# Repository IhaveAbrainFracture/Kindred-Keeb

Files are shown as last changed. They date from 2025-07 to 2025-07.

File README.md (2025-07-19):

# Kindred-Keeb
A keyboard themed and designed around the league of legends character Kindred, made for a certain someone <3







# why i made this
So the chronic ado fan this is going to is a keyboard fan and arguably a nerd in all things keyboard related and im not, this project was in part 1. to make a rly good gift but even more 2. to understand keyboards (the in's and the out's) such that when she eventually starts rambling again i can understand all the keyboard things she spews out.

View the full cad here (open in a new tab) : https://cad.onshape.com/documents/49660f55174e9c1ee612018b/w/865d86d8a66051a73309fb28/e/2b79c125cb158cfc9eb8a47f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

# Specificaton (Firmware)
1. 3 LAYERS OF FULL CUSTOMISABILITY!!!!!
2. 5 intergrated macros
3. kmk and fully open source
   


# Specifications (Electronics)
1. Hot swappable (you dont need to get married to the first switch you solder)
2. cool silk layer
3. run by a pico


# Specifications (Mechanical)
1. minimal bolts and others
2. textured arm rest that is magnetically held
3. only 4 major printed parts
4. custom keycaps
5. very thematicaly/lore accurate
   




# instructions to build
1.using the dowels and such attach the 2 major case and plate parts together then if possible 'melt' then together (like press a iron on both or smthing)

2. in the allocated area insert the insert nuts
   
3.cut and place the foam in the alloacted area then place the pcb on the groves outlines for it

4. place the fully assembled plate ontop of the pcb before placing all the switches
   
5. place the plate pcb sandwitch on the case and bolt into the allocated bolt holes and pray

# BOM 
| Item | Amount | Cost (AUD) | Cost (USD) | Link |
|---|---|---|---|---|
|Magnets| 50 (i cant order less)  | $3.32 | .. | [here](https://www.aliexpress.com/item/1005009515673951.html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"order"%3A"-1"%2C"eval"%3A"1"%7D&pdp_npi=4%40dis%21AUD%215.35%213.32%21%21%213.43%212.13%21%402101c5bf17528901380865997ea1e8%2112000049339085641%21sea%21AU%216189345413%21X&curPageLogUid=kPWgozpKm8qq&utparam-url=scene%3Asearch%7Cquery_from%3A) |
| Stabilisers|  1x | 9.69 | | [Here](https://www.aliexpress.com/item/1005009309795353.html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) |
| Akko blue switches | 45x | 23.19 | | [here](https://www.aliexpress.com/item/1005005514262670.html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"cart2PdpParams"%3A%7B"pdpBusinessMode"%3A"retail"%7D%7D) |
| Keycaps 132 key purple  | 1x | 20.61 | | [here](https://www.aliexpress.com/item/1005004537134105.html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) |
|  Raspberry pi pico | 1x | 2.84 | | [here](https://www.aliexpress.com/item/1005008478649106.html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) |
| 50 m2 bolts| 1x | 2.29 | | [here](https://www.aliexpress.com/item/32810872544.html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) |
| 50x 3.2 od m2 insert nut  | x1 | 2.29 | |  [here](https://www.aliexpress.com/item/1005008666672949.html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) |
| 100x n4148 diodes  | x1 | 2.79 | |  [here](https://www.aliexpress.com/item/4000142272546.html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) |
|  desoldering braid wick | x1 | 4.43 | | [here](https://www.aliexpress.com/item/1005006427770026.html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) |
| Akko purple switch  | 45x |  25.59 | | [here](https://www.aliexpress.com/item/1005007551750020.html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) |
| kailh hot swap socket | 70x | 5.54 | |  [here](https://www.aliexpress.com/item/1005007225352311.html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) |
| 2mm thick eva foam  | 1x | 4.79 | | [here](https://www.aliexpress.com/item/1005009318717019.html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)  |
|  silent lemon v3 switch  |  10x  |  4.86 | | [here](https://www.aliexpress.com/item/1005007459638140.html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)  |
| PCB | 5x | 59.86 | | 
  |
|  3D Printing   |   a lot     |     Free         |            |   Printing legion   |

Total: 

AUD: 181.82 (WITH SHIPPING)

USD:118.84 (WITH SHIPPING)

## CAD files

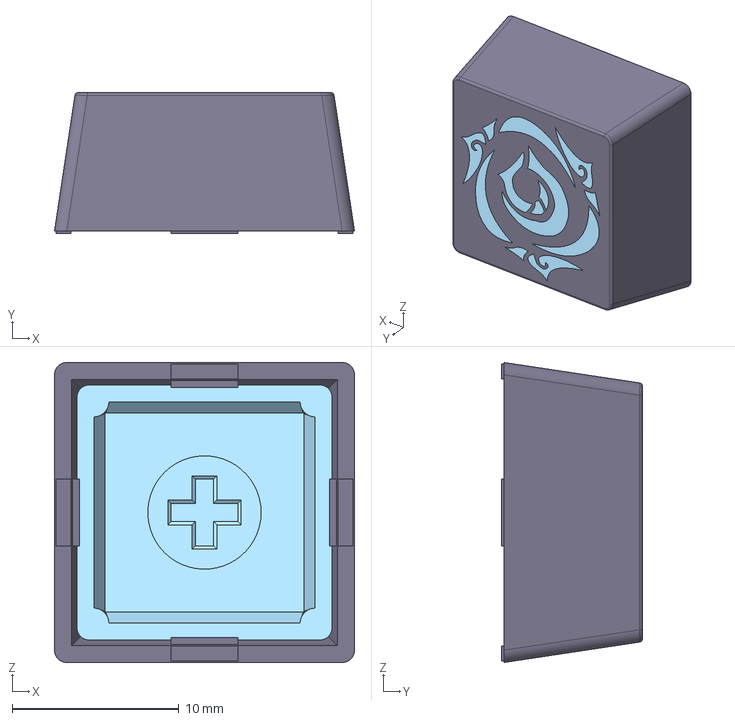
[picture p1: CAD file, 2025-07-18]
Production files/CAD FILES/Keycap (hunters mark).step
18.0 x 8.45 x 18.0 mm

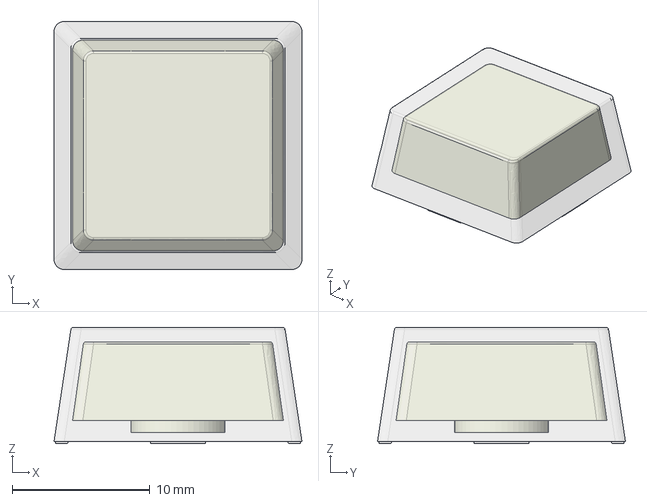
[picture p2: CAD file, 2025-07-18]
Production files/CAD FILES/Keycap.step
18.0 x 18.0 x 8.45 mm
beschr. Kappe Abdeckung
beschr. Kappe Unterteil

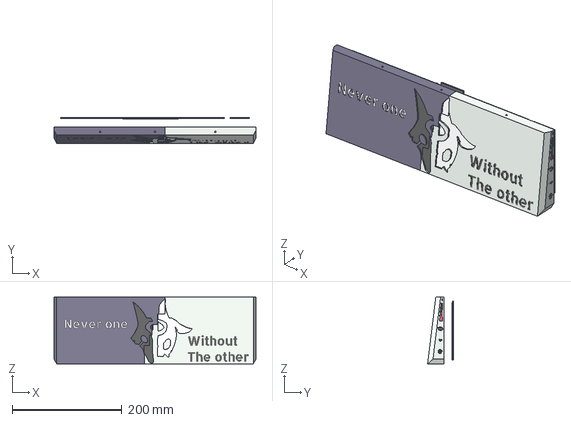
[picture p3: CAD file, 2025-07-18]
Production files/CAD FILES/Keyboard case.step
367.9 x 47.0 x 121.6 mm

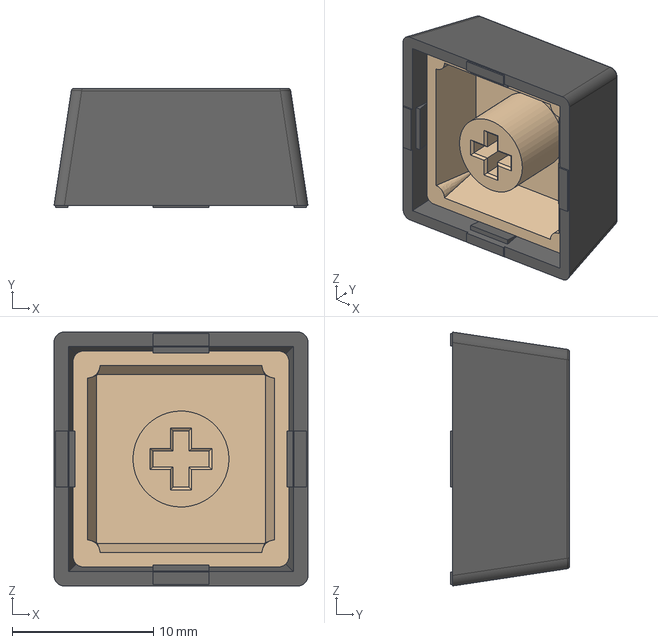
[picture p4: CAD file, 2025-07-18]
Production files/CAD FILES/precision keycap.step
18.0 x 8.45 x 18.0 mm

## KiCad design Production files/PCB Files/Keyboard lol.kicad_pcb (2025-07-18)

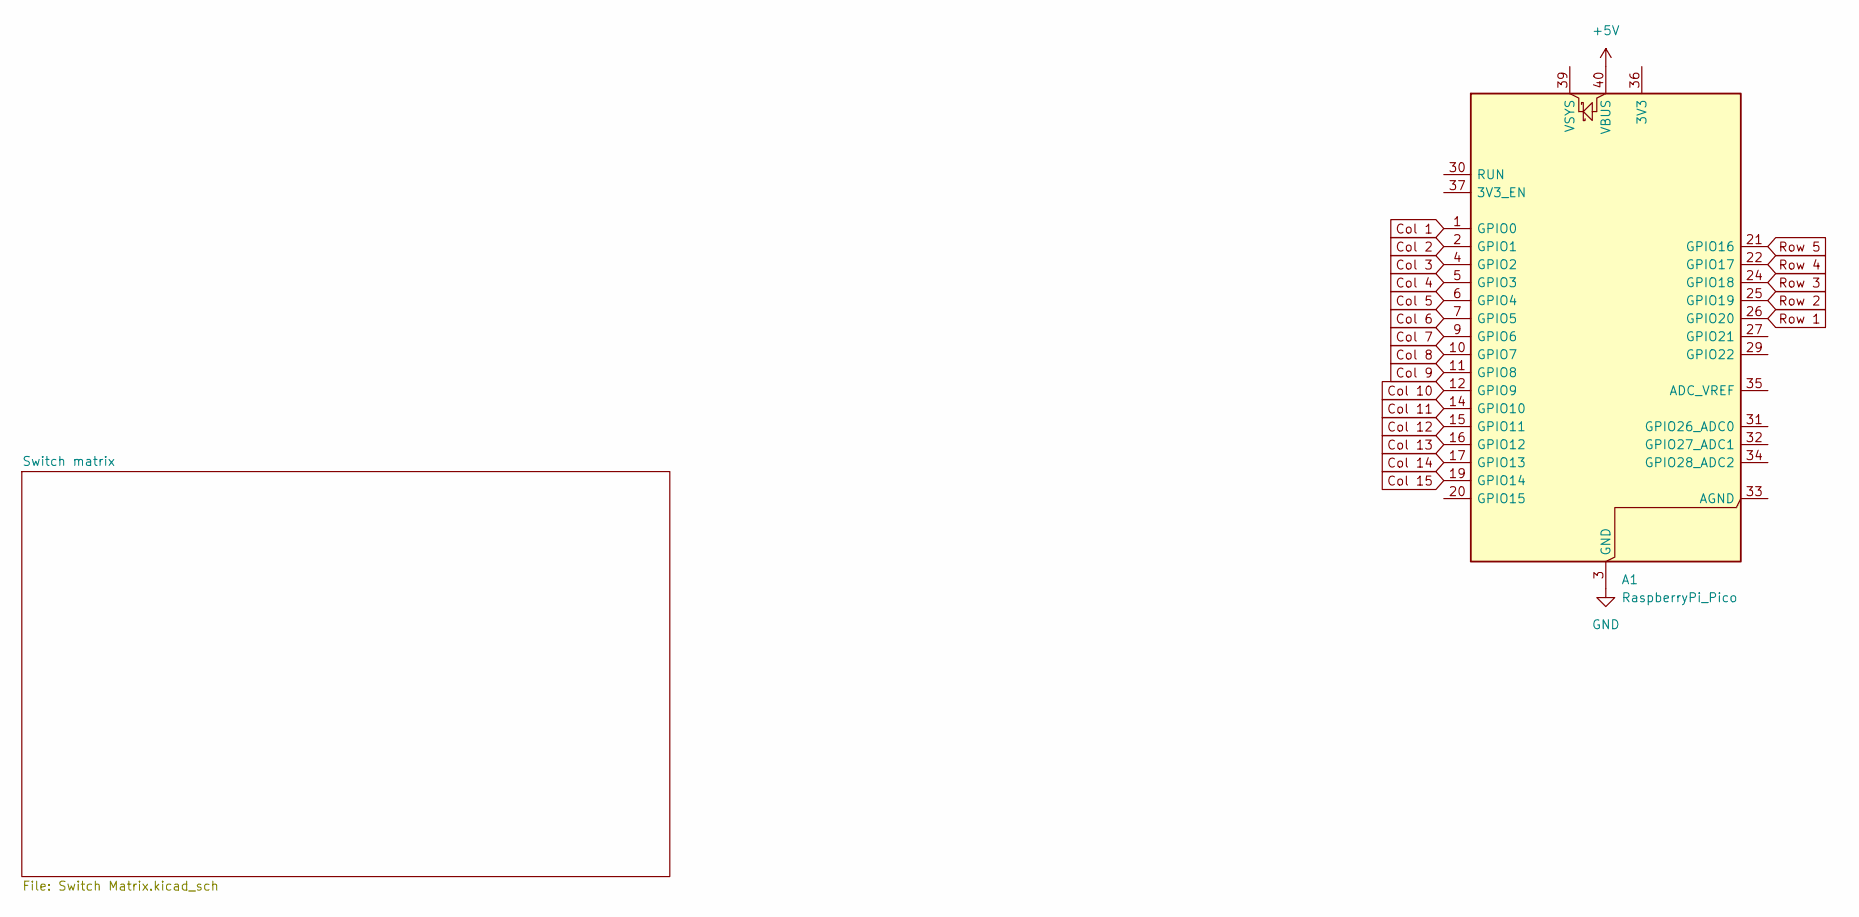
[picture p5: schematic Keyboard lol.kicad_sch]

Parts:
A1: RaspberryPi_Pico; RaspberryPi_Pico_Common_THT

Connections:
+5V: A1.40 (VBUS)
Col 1: A1.1 (GPIO0); also elsewhere on the board
Col 2: A1.2 (GPIO1); also elsewhere on the board
Col 3: A1.4 (GPIO2); also elsewhere on the board
Col 4: A1.5 (GPIO3); also elsewhere on the board
Col 5: A1.6 (GPIO4); also elsewhere on the board
Col 6: A1.7 (GPIO5); also elsewhere on the board
Col 7: A1.9 (GPIO6); also elsewhere on the board
Col 8: A1.10 (GPIO7); also elsewhere on the board
Col 9: A1.11 (GPIO8); also elsewhere on the board
Col 10: A1.12 (GPIO9); also elsewhere on the board
Col 11: A1.14 (GPIO10); also elsewhere on the board
Col 12: A1.15 (GPIO11); also elsewhere on the board
Col 13: A1.16 (GPIO12); also elsewhere on the board
Col 14: A1.17 (GPIO13); also elsewhere on the board
GND: A1.3 (GND), A1.8 (GND), A1.13 (GND), A1.18 (GND), A1.23 (GND), A1.28 (GND), A1.38 (GND)
Row 1: A1.26 (GPIO20); also elsewhere on the board
Row 2: A1.25 (GPIO19); also elsewhere on the board
Row 3: A1.24 (GPIO18); also elsewhere on the board
Row 4: A1.22 (GPIO17); also elsewhere on the board
Row 5: A1.21 (GPIO16); also elsewhere on the board

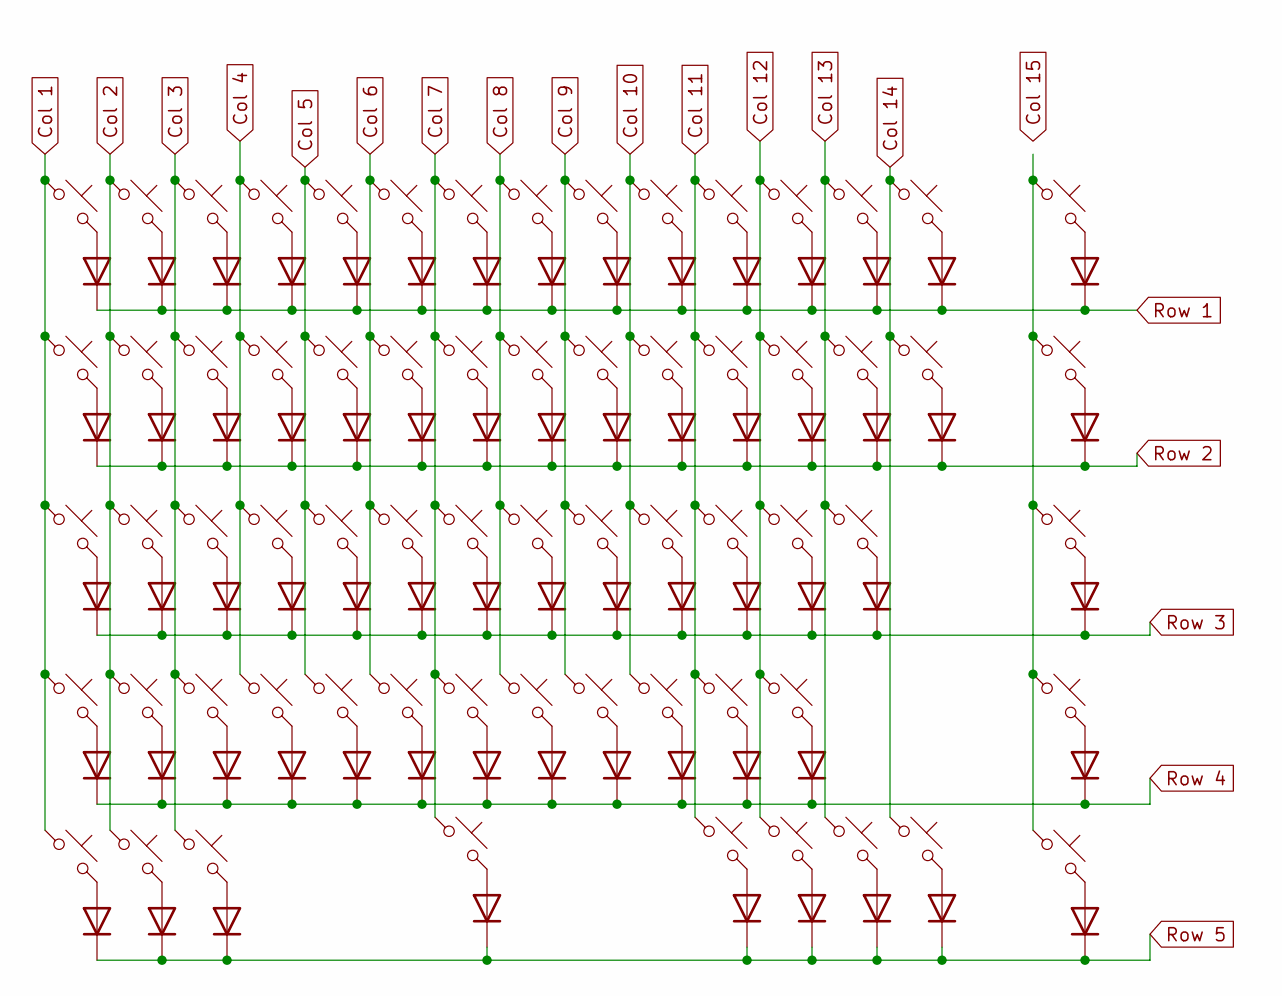
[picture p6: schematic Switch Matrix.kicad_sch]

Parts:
D1, D2, D3, D4, D5, D6, D7, D8, D9, D10, D11, D12, D13, D14, D15, D16, D17, D18, D19, D20, D21, D22, D23, D24, D25, D26, D27, D28, D30, D31, D32, D33, D34, D35, D36, D37, D38, D39, D40, D41, D42, D45, D46, D47, D48, D49, D50, D51, D52, D53, D54, D55, D56, D57, D58, D59, D60, D61, D62, D63, D64, D65, D66, D67, D68, D75: 1N4148; D_DO-35_SOD27_P7.62mm_Horizontal
SW1, SW14: SW_Push_45deg; MX-Hotswap-1.5U
SW2, SW3, SW4, SW5, SW6, SW7, SW8, SW9, SW10, SW11, SW12, SW13, SW15, SW17, SW18, SW19, SW20, SW21, SW22, SW23, SW24, SW25, SW26, SW27, SW30, SW32, SW33, SW34, SW35, SW36, SW37, SW38, SW39, SW40, SW41, SW45, SW46, SW47, SW48, SW49, SW50, SW51, SW52, SW53, SW54, SW55, SW56, SW57, SW58, SW60, SW75: SW_Push_45deg; MX-Hotswap-1U
SW16: SW_Push_45deg; MX-Hotswap-1.75U
SW28, SW31: SW_Push_45deg; MX-Hotswap-2.25U
SW42: SW_Push_45deg; MX-Hotswap-2.75U
SW59: SW_Push_45deg; MX-Hotswap-2U
SW61, SW62, SW63, SW65, SW66, SW67, SW68: SW_Push_45deg; MX-Hotswap-1.25U
SW64: SW_Push_45deg; MX-Hotswap-6.25U-ReversedStabilizers

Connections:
Col 1: SW1.1, SW16.1, SW31.1, SW46.1, SW61.1; also elsewhere on the board
Col 2: SW2.1, SW17.1, SW32.1, SW47.1, SW62.1; also elsewhere on the board
Col 3: SW3.1, SW18.1, SW33.1, SW48.1, SW63.1; also elsewhere on the board
Col 4: SW4.1, SW19.1, SW34.1, SW49.1; also elsewhere on the board
Col 5: SW5.1, SW20.1, SW35.1, SW50.1; also elsewhere on the board
Col 6: SW6.1, SW21.1, SW36.1, SW51.1; also elsewhere on the board
Col 7: SW7.1, SW22.1, SW37.1, SW52.1, SW64.1; also elsewhere on the board
Col 8: SW8.1, SW23.1, SW38.1, SW53.1; also elsewhere on the board
Col 9: SW9.1, SW24.1, SW39.1, SW54.1; also elsewhere on the board
Col 10: SW10.1, SW25.1, SW40.1, SW55.1; also elsewhere on the board
Col 11: SW11.1, SW26.1, SW41.1, SW56.1, SW65.1; also elsewhere on the board
Col 12: SW12.1, SW27.1, SW42.1, SW57.1, SW66.1; also elsewhere on the board
Col 13: SW13.1, SW28.1, SW58.1, SW67.1; also elsewhere on the board
Col 14: SW14.1, SW59.1, SW68.1; also elsewhere on the board
unnamed: D1.2 (A), SW1.2
unnamed: D2.2 (A), SW2.2
unnamed: D3.2 (A), SW3.2
unnamed: D4.2 (A), SW4.2
unnamed: D5.2 (A), SW5.2
unnamed: D6.2 (A), SW6.2
unnamed: D7.2 (A), SW7.2
unnamed: D8.2 (A), SW8.2
unnamed: D9.2 (A), SW9.2
unnamed: D10.2 (A), SW10.2
unnamed: D11.2 (A), SW11.2
unnamed: D12.2 (A), SW12.2
unnamed: D13.2 (A), SW13.2
unnamed: D14.2 (A), SW14.2
unnamed: D15.2 (A), SW15.2
unnamed: D16.2 (A), SW16.2
unnamed: D17.2 (A), SW17.2
unnamed: D18.2 (A), SW18.2
unnamed: D19.2 (A), SW19.2
unnamed: D20.2 (A), SW20.2
unnamed: D21.2 (A), SW21.2
unnamed: D22.2 (A), SW22.2
unnamed: D23.2 (A), SW23.2
unnamed: D24.2 (A), SW24.2
unnamed: D25.2 (A), SW25.2
unnamed: D26.2 (A), SW26.2
unnamed: D27.2 (A), SW27.2
unnamed: D28.2 (A), SW28.2
unnamed: D30.2 (A), SW30.2
unnamed: D31.2 (A), SW31.2
unnamed: D32.2 (A), SW32.2
unnamed: D33.2 (A), SW33.2
unnamed: D34.2 (A), SW34.2
unnamed: D35.2 (A), SW35.2
unnamed: D36.2 (A), SW36.2
unnamed: D37.2 (A), SW37.2
unnamed: D38.2 (A), SW38.2
unnamed: D39.2 (A), SW39.2
unnamed: D40.2 (A), SW40.2
unnamed: D41.2 (A), SW41.2
unnamed: D42.2 (A), SW42.2
unnamed: D45.2 (A), SW45.2
unnamed: D46.2 (A), SW46.2
unnamed: D47.2 (A), SW47.2
unnamed: D48.2 (A), SW48.2
unnamed: D49.2 (A), SW49.2
unnamed: D50.2 (A), SW50.2
unnamed: D51.2 (A), SW51.2
unnamed: D52.2 (A), SW52.2
unnamed: D53.2 (A), SW53.2
unnamed: D54.2 (A), SW54.2
unnamed: D55.2 (A), SW55.2
unnamed: D56.2 (A), SW56.2
unnamed: D57.2 (A), SW57.2
unnamed: D58.2 (A), SW58.2
unnamed: D59.2 (A), SW59.2
unnamed: D60.2 (A), SW60.2
unnamed: D61.2 (A), SW61.2
unnamed: D62.2 (A), SW62.2
unnamed: D63.2 (A), SW63.2
unnamed: D64.2 (A), SW64.2
unnamed: D65.2 (A), SW65.2
unnamed: D66.2 (A), SW66.2
unnamed: D67.2 (A), SW67.2
unnamed: D68.2 (A), SW68.2
unnamed: D75.2 (A), SW75.2
Row 1: D46.1 (K), D47.1 (K), D48.1 (K), D49.1 (K), D50.1 (K), D51.1 (K), D52.1 (K), D53.1 (K), D54.1 (K), D55.1 (K), D56.1 (K), D57.1 (K), D58.1 (K), D59.1 (K), D60.1 (K); also elsewhere on the board
Row 2: D1.1 (K), D2.1 (K), D3.1 (K), D4.1 (K), D5.1 (K), D6.1 (K), D7.1 (K), D8.1 (K), D9.1 (K), D10.1 (K), D11.1 (K), D12.1 (K), D13.1 (K), D14.1 (K), D15.1 (K); also elsewhere on the board
Row 3: D16.1 (K), D17.1 (K), D18.1 (K), D19.1 (K), D20.1 (K), D21.1 (K), D22.1 (K), D23.1 (K), D24.1 (K), D25.1 (K), D26.1 (K), D27.1 (K), D28.1 (K), D30.1 (K); also elsewhere on the board
Row 4: D31.1 (K), D32.1 (K), D33.1 (K), D34.1 (K), D35.1 (K), D36.1 (K), D37.1 (K), D38.1 (K), D39.1 (K), D40.1 (K), D41.1 (K), D42.1 (K), D45.1 (K); also elsewhere on the board
Row 5: D61.1 (K), D62.1 (K), D63.1 (K), D64.1 (K), D65.1 (K), D66.1 (K), D67.1 (K), D68.1 (K), D75.1 (K); also elsewhere on the board

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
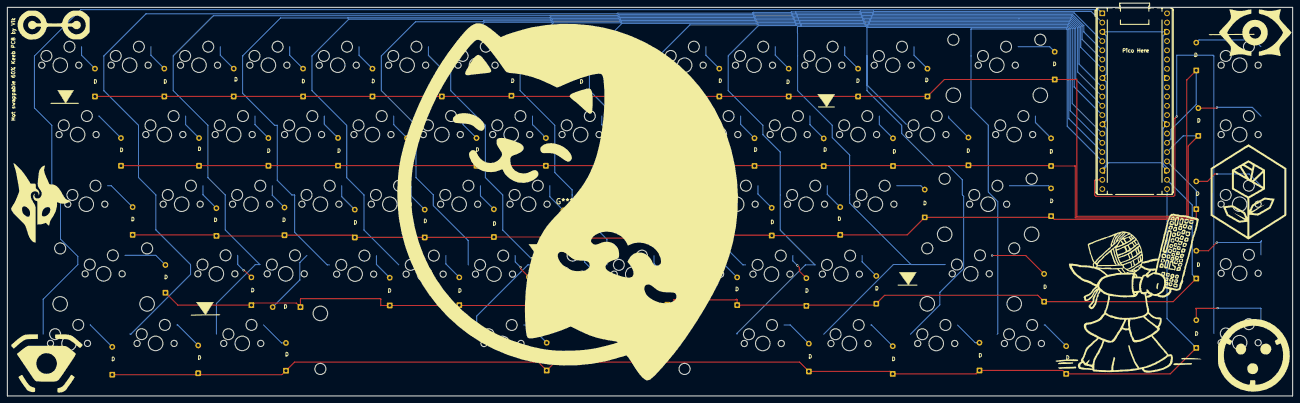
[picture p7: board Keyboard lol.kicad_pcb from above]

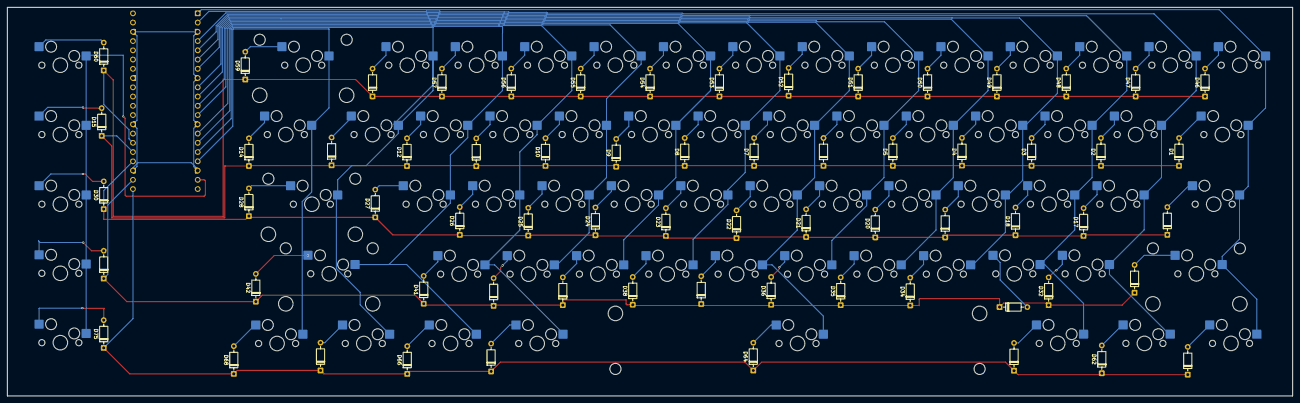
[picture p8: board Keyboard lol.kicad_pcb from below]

Board: 2 copper layers, 352.9 x 106.7 mm, 133 parts (132 on the bottom side), 87 nets.

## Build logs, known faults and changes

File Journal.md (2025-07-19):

---
title: "Kindred Keeb"
author: "TheVirtuoso (me)"
description: "A keyboard that thematicaly fits the charecter kindred from lol"
created_at: "13/07/25"
---

total hours ~ 45  (these hours are like not locked in locked in hours cos i was very non strict in time in reality this project could be done in 30h)

# background information that you may want to know to that some things make more sense
- kindred is a league of legends charecter who lore wise is just death
- the idea is when someone is about to die they can choose to me killed swiftly by lamb's bow or resist dead and fight wolf in more or less a bloodbath
- in the game one of her core mechanics is the mark of the hunted which is a big target sign
- in lol after picking a charecter you pick runes which slightly modify a charecter
- kindred is a top tier meta pick rn trust

# mildly important note
** So im updating the journal to reflect what ive done anything with "OLD:" is the old entry which i kept because its a little more authentic as it was done on the day (most likely at 12 or 1 AM) but for all non troll reasons read the new entry since its a better explainantion on what i did and how that went **

 OLD: so i've been procrastinating making and updating the journal for the first few days because just like today (15/07/25) ive staid up till 12pm to work on stuff either way ill recap the last 2 days which had me working on electronics (PCB)

# 13/07/25 2h
Old : i more or less spent this day just brainstorming what i was going to do because i knew i was going to make a custom keyboard for my gf but i didnt know what to theme it off of ect i came to the following conclusions after a hour of brainstorming
 - the keyboard is going to be based on a game preferably one with chatecters so i can theme it off her "main"
 - options include: Kindred, Cypher, kai'sa, The Engineneer and Clove
 - i want the pcb to be as good as possible so i can use it for myself later
 - most likely going to use tactile switches
 - i want it to be hot swappable
 - i should make accessories that add on to the keeb (arm rest)
   
New: 

this day was spent brainstorming the main take aways was that i knew the keeb (keyboard) was going to be based on a charecter from a game most likely league of legends or valorant ( in ended up being kindred from lol altho it was very close to being based on clove, the color profiles are below). Further more i knew i wanted the PCB to be good enough that it could be used in future projects meaning i wanted it to be versitile and high quality ie hot swappable and good layout
- 
- 
Above is the colour profile for clove

- 
- 

Above is the colour proflie for kindred

Theme wise i also had 2 options the duality, yin yang-ish theme or the butterflys and repetion theme (these being from kindred and clove respectfully)\
ultimatly i picked kindred cos ann (nickname) play way more lol then valo also i though it would be easier to design (i was wrong)

here were the broad design choices after deciding to base the keeb of kindred
- case divided into 2 parts (wolf and Lamb)
- 2 diffrent switchs one that heavy and loud/thocky and one thats light and silent
- the masks need to be somewhere, and the cool quotes
- it would be nice to have the keeb textured
- the mark of the hunted needs to be everywhere on keycaps and case

# 14/07/25 16h
  OLD: ill put photos here late but this day mostly consisted of research and making the schematics/pcb ill pop photos in the morning but more or less i have a terrible time trying to position and align everything, ultimatly i did get most of the pcb and schematics done. (funny note, i spent 1h just on messing with footprints) either way i think i ended this day with the matrix wired in the pcb and the footprints more or less is the right spot but nothing was connected to the pico and i still had to run through the 20 drc issues  also cleaned up the pcb specifically wiring everything to the pico, drc, and silk screen( i added so many easter eggs) i also posted the pcb to the atlier discord server for feedback and implemented that

New:
Started PCB it was mostly easy the core concepts are the same, im also hyper gratfull that i learnt how to wire matrixes and stuff early,

Schematic here:

-  
(fun fact you can make a seperate sheet for your schematic using "s" , thats were my matrix is)
I also experimented with the idea of leds but i just couldnt figure a way to make it fit the theme heres that schematic either way

- 
i also got most of the keyboard pcb done which looks like this
- 
you also might notice the fact that col 15 isnt connected in the matrix above and ye i just fixed that (18/07/25) 
with silk it looks like this
- 
- Explaination of silk (she loves cats, use to main cypher in valorant hence the abilitys in the corners, currently is training in kendo, and the kindred mask exists)
i also put stuff into the atelier discord for review and implemented that feedback.( to anyone who wants to also make a keyboard my suggestion is to pick the ai03 footprints and stick to them)

  # 15/07/25 10h
 OLD: i spend way to long cadding to make the case and all, ill add more stuff her later but its 12:30 and i need to get sleep cos i got stuff to do so ill update this with tmmrws update, ill also add photots and clean up spelling 

New: this day was spent cadding and designing i more or less spent this day messing around with cad stuff but the issue is i dont rly haev anything so show since i didnt take any screenshots so heres my proof
 
we love onshape history 

  # 16/07/25 5h
  OLD: trust me i did stuff but this is another i stayed up till 12 situation so ill update this later the tldr is the base of the case is more or less done its just design stuff lef
  
- New: again dont have alot to show here but i can replicate it:

 it was at this point i more or less had my main case done ( the shell more or less) i also started the arm rest which i do have photos of

 



   # 17/07/25 15h

 OLD:  this entry got deleted so like gotta add stuff
New: so this carries on to the next entry since i wrote 18 cos it was 1 am either way this day i finished all is not most of the design/cosmetic stuff best shown though photos, ill also be explaining some of the cool things



- so this is the mark of the hunted and i wanted it to be a core part of the case so its in the center and the middle

- 

- so this is a mix of wolfs and lambs mask with one of their most common voicelines "never one without the other" its also black and white to reflect the duality theme i started with

- 
- 

these are lol runes and are also the best/ most common rune build for kindred

- 
-  mark of the hunted custom keycap

-  

-  

- Arm rest modifications

- and with that i should be done in cad also note 



FOAMMMMMM!!!!!

  # 18/07/25 3h
  OLD: im going to sleep instead i swear update soon

  # 18/07/25 4h
OLD: gues what its not 12 an im done so i can spend time now cleaning the github

New: i didnt do too much other than clean the github and start and finish firmware which is here: (funny story i was doing firmware while in the hospital)


# 19/07/25
did bom and prob gonna submit today not counting time towards project

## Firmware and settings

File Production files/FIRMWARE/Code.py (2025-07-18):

print("Starting")

import board

from kmk.kmk_keyboard import KMKKeyboard
from kmk.keys import KC, Keyboard
from kmk.scanners import DiodeOrientation
from kmk.modules.macros import Macros
from kmk.modules.macros import Press, Release, Tap  #underdefined
from kmk.modules.layers import layers 

# all imports
keyboard = KMKKeyboard()
macros = Macros()
keyboard.modules.append(macros)
keyboard.col_pins = (board.GP0, board.GP1, board.GP2, board.GP3, board.GP4, board.GP5,board.GP6, board.GP7,board.GP8, board.GP9,board.GP10,board.GP11, board.GP12, board.GP13, board.GP14 )
keyboard.row_pins = (board.GP16, board.GP17, board.GP18, board.GP19, board.GP20)
keyboard.diode_orientation = DiodeOrientation.COL2ROW   # i think its col2row
keyboard.modules.append(layers)

PASTE =KC.MACRO(
  (
    KC.LCTL(KC.V)),
  )

COPY =KC.MACRO(
  (
    KC.LCTL(KC.C)),
  )


Ctrl_Tab =KC.MACRO(
  (
    KC.LCTL(KC.TAB)),
  )

Alt_Tab =KC.MACRO(
  (
    KC.LALT(KC.LTAB),
  )
)

SAVE = KC.MARCO (
    (
        KC.LCTL(KC.S)
    )
)

keyboard.keymap =     [ [
        KC.ESC,  KC.N1,   KC.N2,   KC.N3, KC.N4, KC.N5,   KC.N6,   KC.N7,   KC.N8,   KC.N9,   KC.N0,   KC.MINS, KC.EQL,  KC.BSPC, PASTE,
        KC.TAB,  KC.Q,   KC.W,    KC.E,    KC.R,    KC.T,    KC.Y,    KC.U,    KC.I,    KC.O,    KC.P,    KC.LBRC, KC.RBRC, KC.BSLS, COPY,
        KC.CAPS, KC.A,   KC.S,    KC.D,    KC.F,    KC.G,    KC.H,    KC.J,   KC.K,   KC.L,    KC.SCLN, KC.QUOT,          KC.ENT,  SAVE,
        KC.LSFT, KC.Z,    KC.X,   KC.C ,  KC.V,    KC.B,    KC.N,    KC.M,    KC.COMM, KC.DOT,  KC.SLSH,      KC.RSFT, KC.MO(1), Alt_Tab,
        KC.LCTL, KC.LGUI, KC.LALT,                            KC.SPC,                             KC.RALT, KC.MO(2), KC.MENU, KC.RCTL, Ctrl_Tab,
    ],
    # L1 function keys
    [
        KC.GRV,  KC.F1,   KC.F2,   KC.F3,   KC.F4,   KC.F5,   KC.F6,   KC.F7,   KC.F8,   KC.F9,   KC.F10,  KC.F11,  KC.F12,  KC.DEL,
        KC.TRNS, KC.TRNS, KC.UP,   KC.TRNS, KC.TRNS, KC.TRNS, KC.TRNS, KC.TRNS, KC.PSCR, KC.SLCK, KC.PAUS, KC.TRNS, KC.TRNS, KC.TRNS,
        KC.TRNS, KC.LEFT, KC.DOWN, KC.RGHT, KC.TRNS, KC.TRNS, KC.TRNS, KC.HOME, KC.PGDN, KC.PGUP, KC.END,  KC.TRNS,          KC.TRNS,
        KC.TRNS, KC.TRNS, KC.TRNS, KC.TRNS, KC.TRNS, KC.TRNS, KC.TRNS, KC.TRNS, KC.TRNS, KC.TRNS, KC.TRNS,          KC.TRNS, KC.TRNS,
        KC.TRNS, KC.TRNS, KC.TRNS,                            KC.TRNS,                            KC.TRNS, KC.TRNS, KC.TRNS, KC.TRNS,
    ],
    # Audio (might update for more stuff)
    [
        KC.TRNS, KC.TRNS, KC.TRNS, KC.TRNS, KC.TRNS, KC.TRNS, KC.TRNS, KC.TRNS, KC.TRNS, KC.TRNS, KC.TRNS, KC.TRNS, KC.TRNS, KC.TRNS,
        KC.TRNS, KC.TRNS, KC.VOLU, KC.TRNS, KC.TRNS, KC.TRNS, KC.TRNS, KC.TRNS, KC.TRNS, KC.TRNS, KC.TRNS, KC.TRNS, KC.TRNS, KC.TRNS,
        KC.TRNS, KC.MPRV, KC.VOLD, KC.MNXT, KC.TRNS, KC.TRNS, KC.TRNS, KC.TRNS, KC.TRNS, KC.TRNS, KC.TRNS, KC.TRNS,          KC.TRNS,
        KC.TRNS, KC.TRNS, KC.TRNS, KC.TRNS, KC.TRNS, KC.TRNS, KC.TRNS, KC.TRNS, KC.TRNS, KC.TRNS, KC.TRNS,          KC.TRNS, KC.TRNS,
        KC.TRNS, KC.TRNS, KC.TRNS,                            KC.MPLY,                            KC.TRNS, KC.TRNS, KC.TRNS, KC.TRNS,
    ],
]


if __name__ == '__main__':
    keyboard.go()

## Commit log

2025-07-18 FIRMWARE
    Everything that needs to be flashed onto your pico
2025-07-18 All relvent Kicad files
    [Keyboard lol.kicad_pcb, Keyboard lol.kicad_sch, Switch Matrix.kicad_sch]
2025-07-18 All cad files
    [Keyboard case.step, Keycap (hunters mark).step, Keycap.step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]
